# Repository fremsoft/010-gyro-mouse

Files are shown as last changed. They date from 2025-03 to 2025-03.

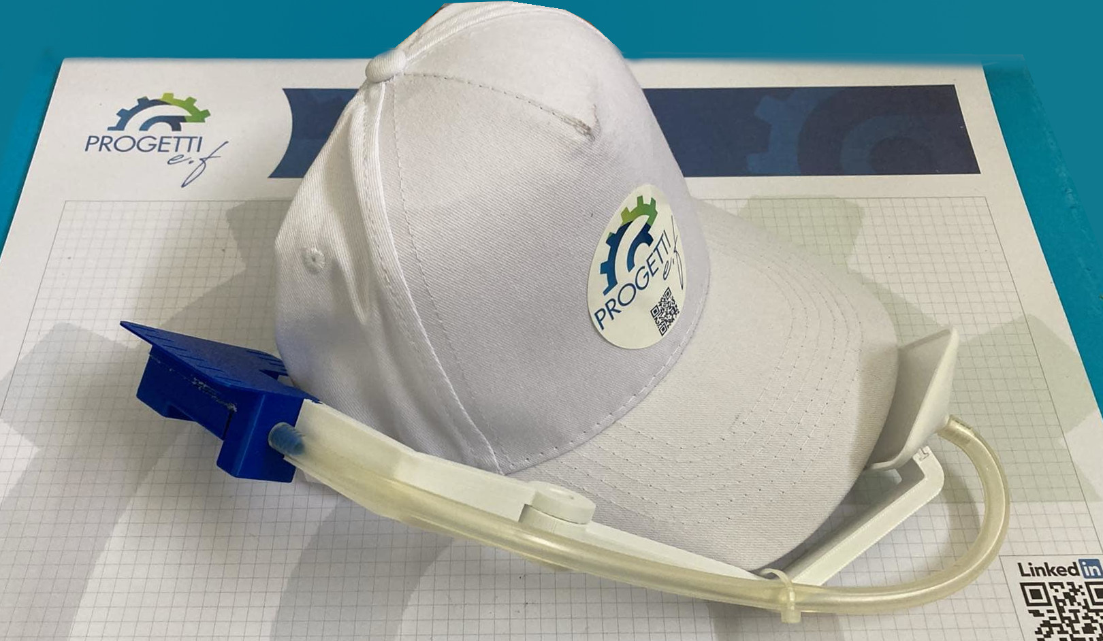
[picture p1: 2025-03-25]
hardware/gyro-mouse.jpg

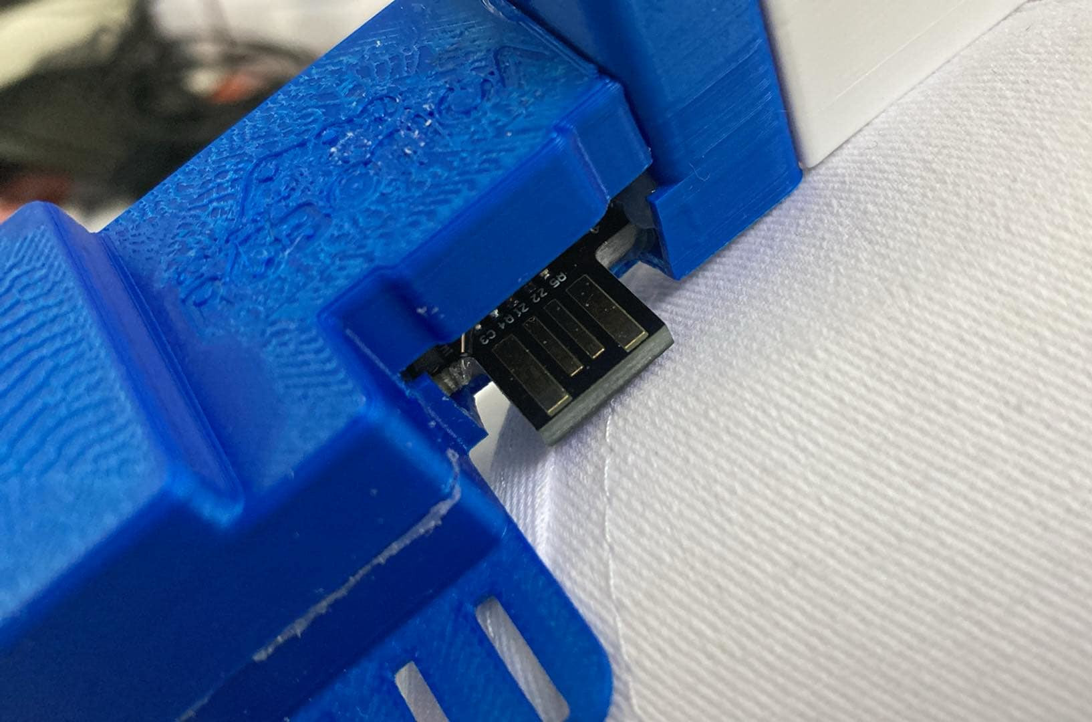
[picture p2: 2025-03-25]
hardware/dettaglio-gyro-mouse.jpg

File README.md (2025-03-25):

# 🖱️ Gyro Mouse – Controllo del Mouse con Inclinazione e Soffio

Il **Gyro Mouse** è un innovativo sistema di puntamento che consente di controllare il cursore del **mouse** attraverso l’**inclinazione della testa** e di simulare i click con il **soffio**. Questo dispositivo è stato progettato per offrire un'alternativa accessibile e intuitiva al tradizionale mouse.

## 📌 Caratteristiche
- **Controllo del cursore** tramite inclinazione della testa (coordinate assolute)
- **Emulazione dei click** con il soffio in un apposito imbuto
- **Compatibile con risoluzione 1920x1080**
- Basato su **Beetle (ATmega32U4)** o **Arduino Micro** o **Arduino Leonardo** per il supporto nativo USB
- Sensori utilizzati:
  - **MPU-6050** per rilevare l’inclinazione X-Y-Z
  - **BMP180** per il riconoscimento del soffio
- Progettato per il **fai-da-te** e l’integrazione in progetti di accessibilità

## 🎮 Modalità di Controllo
- **Inclinazione della testa** → Sposta il mouse su schermo
- **1 soffio breve** → Click sinistro
- **2 soffi brevi** → Doppio click
- **3 soffi brevi** → Click destro
- **Soffio prolungato** → Trascinamento

## 📂 Struttura del Repository
- `code/` → Contiene il codice sorgente del firmware
- `hardware/` → Schemi e dettagli sui componenti
- `docs/` → Guide e documentazione tecnica

## 🔧 Requisiti
Per costruire e utilizzare il Gyro Mouse, avrai bisogno di:
- **Beetle (ATmega32U4)**
- **MPU-6050 (accelerometro e giroscopio)**
- **BMP180 (sensore di pressione barometrica)**
- **Arduino IDE** per programmare il firmware
- **Cavi e connettori** per il cablaggio

## 📖 Istruzioni per l’Uso
1. **Scarica il codice** da questo repository
2. **Carica il firmware** su Beetle con Arduino IDE
3. **Collega i sensori** secondo lo schema fornito
4. **Indossa il dispositivo e testa il controllo del mouse** 🖱️

## 🎥 Video Dimostrativi
Guarda il progetto in azione su YouTube:
- [Gyro Mouse – in costruzione](#)

## 💡 Contribuisci
Vuoi migliorare il progetto? Sentiti libero di **fare fork del repository** e proporre modifiche tramite una pull request! Idee, miglioramenti e test sono sempre benvenuti.

## 📩 Contatti
Per domande, suggerimenti o collaborazioni, puoi contattarmi tramite [email] o aprire una issue su GitHub.

---  
✨ _Impara Giocando – Scuola di Robotica e Meccatronica_ ✨

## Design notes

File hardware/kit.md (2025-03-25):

# Materiale Utilizzato

Questo progetto utilizza componenti specifici per la realizzazione di un sistema basato su Arduino Micro/Leonardo con ATmega32U4.
Di seguito trovi l'elenco dei materiali necessari con i relativi link per l'acquisto.

## 🛠️ Componenti

- [ARDUINO BEETLE](https://amzn.to/4c5joW2) 
- [ARDUINO MICRO](https://amzn.to/421yWWj) 
- [MPU-6050](https://amzn.to/4iZpiKA)
- [BMP180](https://amzn.to/4iZpiKA)

Questi componenti vanno assemblati seguendo le indicazioni riportate nel video.

Buon divertimento con il tuo progetto! 🚀

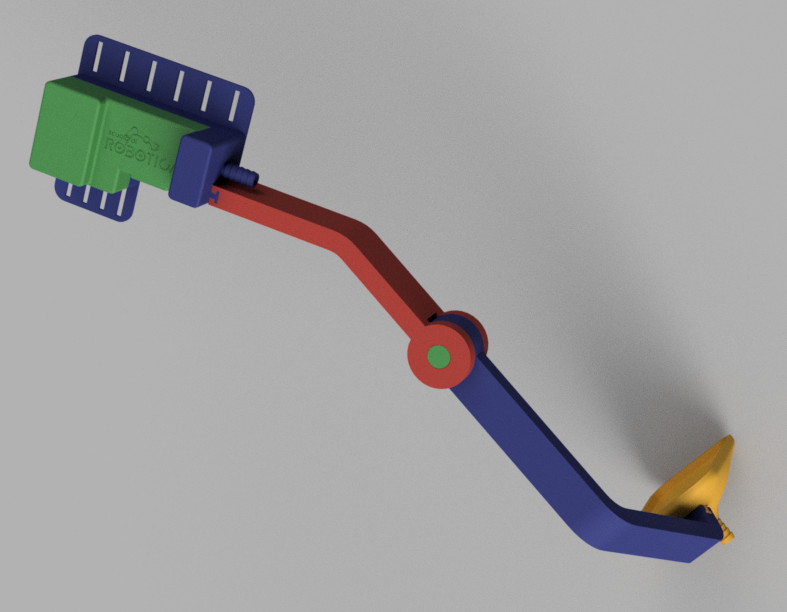
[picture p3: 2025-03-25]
hardware/GYRO-MOUSE v20.jpg

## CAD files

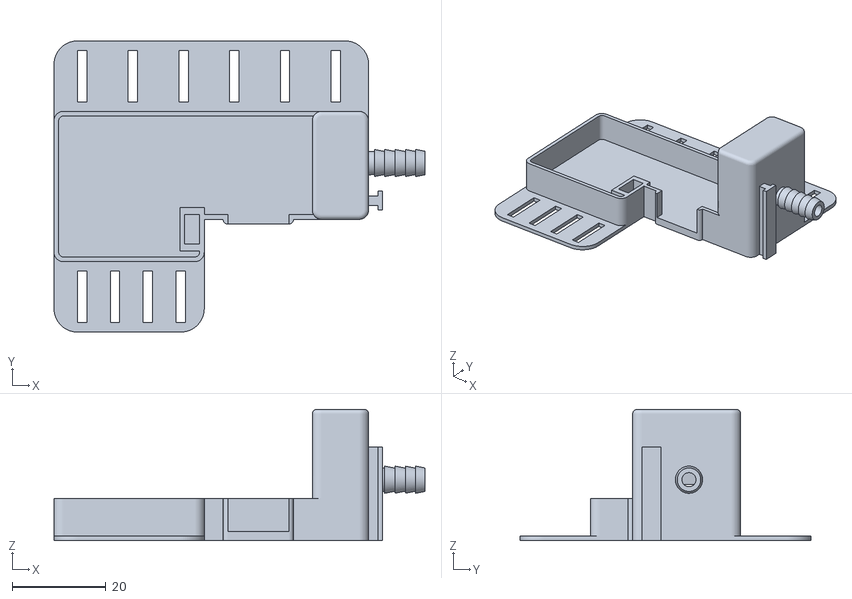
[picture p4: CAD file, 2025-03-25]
hardware/fusion360/stl/part1.stl
79.0 x 62.0 x 28.0

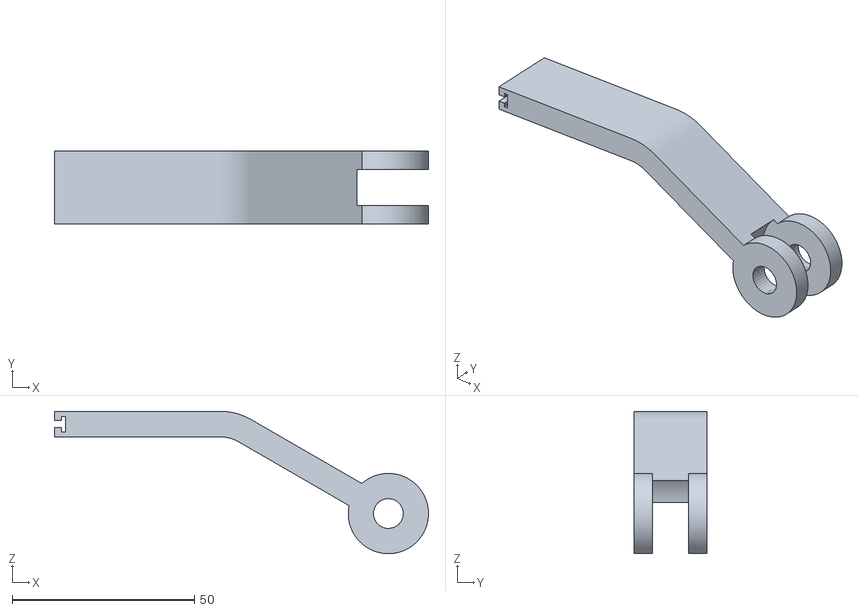
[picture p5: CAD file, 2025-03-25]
hardware/fusion360/stl/part5.stl
102.6 x 20.0 x 39.0

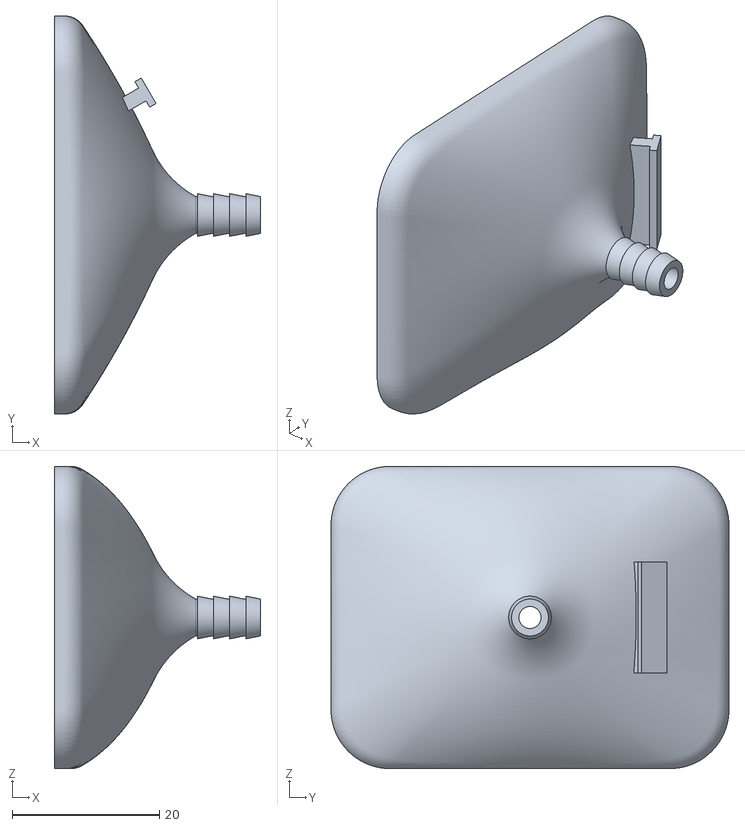
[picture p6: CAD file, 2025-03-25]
hardware/fusion360/stl/part4.stl
28.0 x 54.0 x 41.0

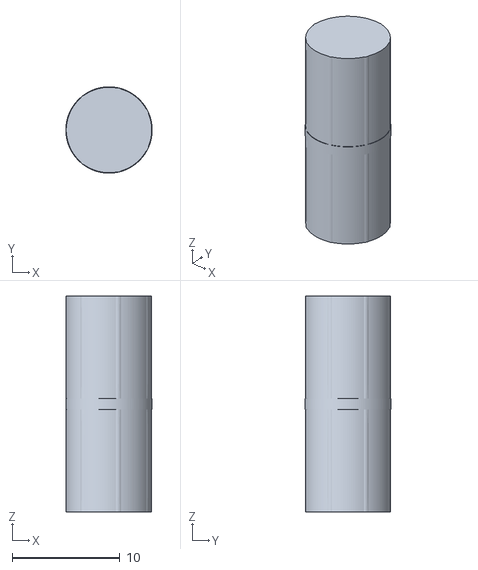
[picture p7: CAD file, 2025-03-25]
hardware/fusion360/stl/part7.stl
8.00 x 8.00 x 20.0

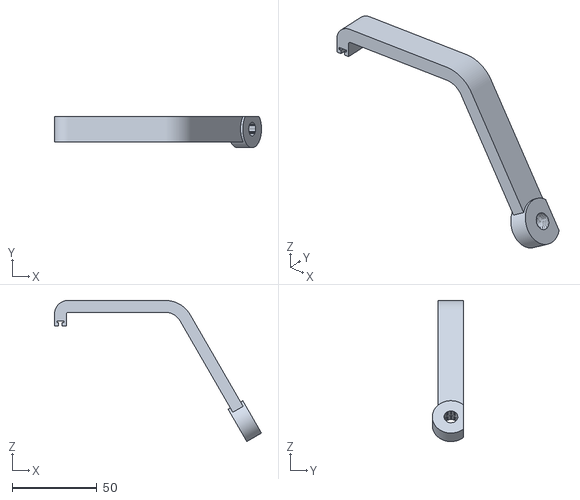
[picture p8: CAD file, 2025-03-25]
hardware/fusion360/stl/part6.stl
121.8 x 18.5 x 83.1

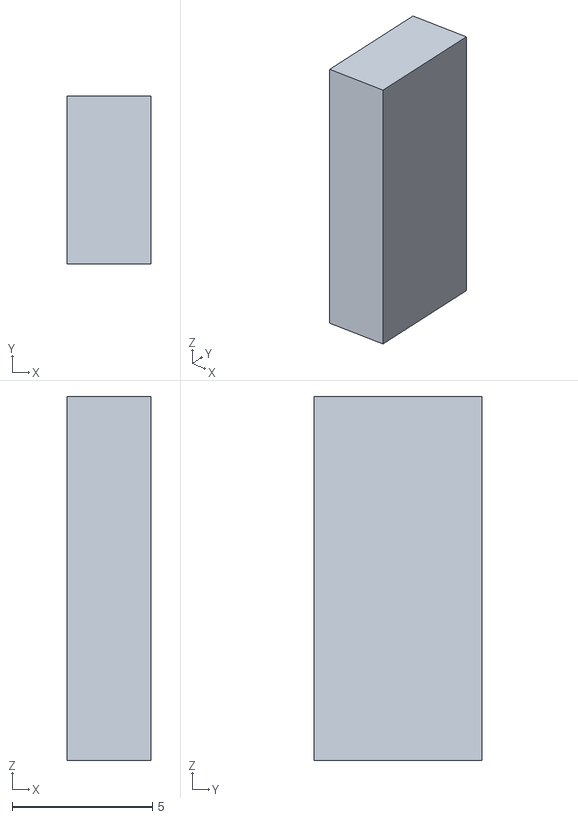
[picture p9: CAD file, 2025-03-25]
hardware/fusion360/stl/part3.stl
3.00 x 6.00 x 13.0

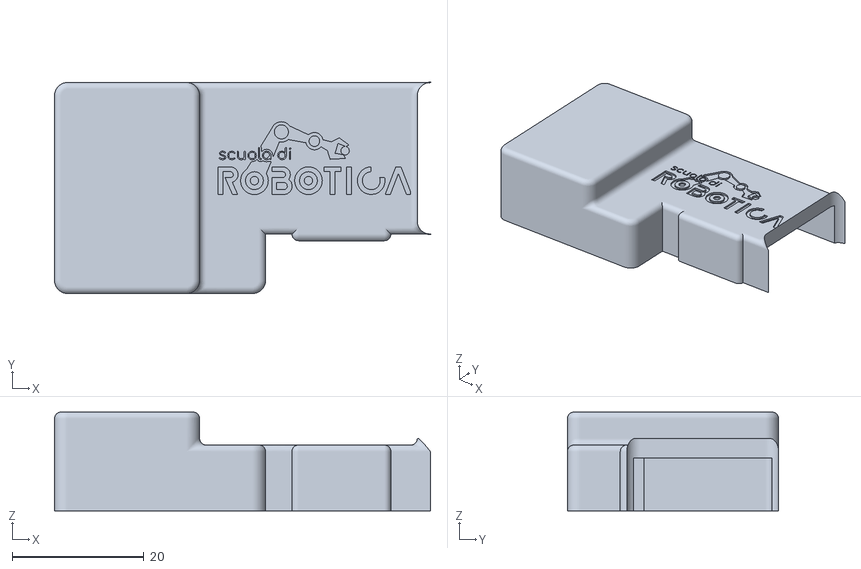
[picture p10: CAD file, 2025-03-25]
hardware/fusion360/stl/part2.stl
57.0 x 32.0 x 15.0

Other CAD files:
hardware/fusion360/GYRO-MOUSE v19.f3z

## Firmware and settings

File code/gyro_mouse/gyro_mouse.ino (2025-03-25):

#include <Adafruit_BMP085.h>
#include <Adafruit_MPU6050.h>
#include <Adafruit_Sensor.h>
#include <Wire.h>

#include <AbsMouse.h>

#define CLICK_TH        60
#define UNCLICK_TH      40
#define T_MIN_CLICK_MS 500

// Connect VCC of the BMP085 sensor to 3.3V (NOT 5.0V!)

Adafruit_BMP085 bmp;
Adafruit_MPU6050 mpu;

int32_t p, fp;
bool clicked;
int32_t t0_click, t1_click, t2_click, t_unclick;
float axf, ayf, azf;
int32_t x, y, xp, yp;


void setup() {
  Serial.begin(9600);

  if (!bmp.begin()) {
    Serial.println("Could not find a valid BMP085 sensor, check wiring!");
    while (1) {}
  }

  if (!mpu.begin()) {
    Serial.println("Failed to find MPU6050 chip");
    while (1) {
      delay(10);
    }
  }
  Serial.println("MPU6050 Found!");

  delay(2000);

  mpu.setAccelerometerRange(MPU6050_RANGE_2_G);
  Serial.print("Accelerometer range set to: ");
  switch (mpu.getAccelerometerRange()) {
    case MPU6050_RANGE_2_G:
      Serial.println("+-2G");
      break;
    case MPU6050_RANGE_4_G:
      Serial.println("+-4G");
      break;
    case MPU6050_RANGE_8_G:
      Serial.println("+-8G");
      break;
    case MPU6050_RANGE_16_G:
      Serial.println("+-16G");
      break;
  }
  mpu.setGyroRange(MPU6050_RANGE_250_DEG);
  Serial.print("Gyro range set to: ");
  switch (mpu.getGyroRange()) {
    case MPU6050_RANGE_250_DEG:
      Serial.println("+- 250 deg/s");
      break;
    case MPU6050_RANGE_500_DEG:
      Serial.println("+- 500 deg/s");
      break;
    case MPU6050_RANGE_1000_DEG:
      Serial.println("+- 1000 deg/s");
      break;
    case MPU6050_RANGE_2000_DEG:
      Serial.println("+- 2000 deg/s");
      break;
  }

  mpu.setFilterBandwidth(MPU6050_BAND_5_HZ);
  Serial.print("Filter bandwidth set to: ");
  switch (mpu.getFilterBandwidth()) {
    case MPU6050_BAND_260_HZ:
      Serial.println("260 Hz");
      break;
    case MPU6050_BAND_184_HZ:
      Serial.println("184 Hz");
      break;
    case MPU6050_BAND_94_HZ:
      Serial.println("94 Hz");
      break;
    case MPU6050_BAND_44_HZ:
      Serial.println("44 Hz");
      break;
    case MPU6050_BAND_21_HZ:
      Serial.println("21 Hz");
      break;
    case MPU6050_BAND_10_HZ:
      Serial.println("10 Hz");
      break;
    case MPU6050_BAND_5_HZ:
      Serial.println("5 Hz");
      break;
  }

  clicked = false;
  t0_click = t1_click = t2_click = t_unclick = 0;

  fp = (float)bmp.readPressure();

  axf = ayf = azf = 0.0;
  x = y = 0;
  xp = yp = -1;

  AbsMouse.init(1920, 1080);  // full HD
}

void loop() {
  int32_t t;
  sensors_event_t a, g, temp;
  mpu.getEvent(&a, &g, &temp);

  axf = ((49.0 * axf) + a.acceleration.x) / 50.0;
  ayf = ((49.0 * ayf) + a.acceleration.y) / 50.0;
  azf = ((49.0 * azf) + a.acceleration.z) / 50.0;

  y = constrain(
    map((long)(10000.0 * atan2(axf, ayf)), -1000, 1000, 1080, 0),
    0, 1080);
  x = constrain(
    map((long)(10000.0 * atan2(azf, ayf)), -1000, 1000, 1920, 0),
    0, 1920);

  p = (float)bmp.readPressure();
  fp = ((fp * 999.0) + p) / 1000.0;

  t = millis();
  if ((!clicked) && (abs(fp - p) > CLICK_TH)) {
    clicked = true;
    if ((t - t2_click) > T_MIN_CLICK_MS) {
      /* primo impulso */
      t0_click = t1_click = t2_click = t;
//Serial.println("primo");
    }
    else if ((t - t0_click) < T_MIN_CLICK_MS) {
      /* secondo impulso */
      t1_click = t2_click = t;
//Serial.println("secondo");
    }    
    else if ((t - t1_click) < T_MIN_CLICK_MS) {
      /* terzo impulso di fila */
      t2_click = t;
//Serial.println("terzo");
    }    
  }
  
  if (clicked) {
    /* se è passato il tempo clicco sinistro */
    if ((t - t0_click) > T_MIN_CLICK_MS) {
      AbsMouse.press(MOUSE_LEFT);
//Serial.println("click");
    }

    /* quando ho rilasciato, entro il tempo aspetto e valuto */
    if (abs(fp - p) < UNCLICK_TH) {
      /* preparo la variabile clicked per accettare altri click */
      clicked = false;
    }
  }
  else {
    /* se è passato il tempo rilascio sinistro */
    if ((t - t2_click) > T_MIN_CLICK_MS) {
      if (t0_click != 0) {
        if (t0_click == t1_click) {
          /* click semplice */
//Serial.println("click semplice");
          AbsMouse.press(MOUSE_LEFT);
          delay(100);
          AbsMouse.release(MOUSE_LEFT);
        }
        else 
        if (t1_click == t2_click) {
          /* doppio click */
//Serial.println("doppio click");
          AbsMouse.press(MOUSE_LEFT);
          delay(100);
          AbsMouse.release(MOUSE_LEFT);
          delay(100);
          AbsMouse.press(MOUSE_LEFT);
          delay(100);
          AbsMouse.release(MOUSE_LEFT);
        }
        else {
          /* triplo click == tasto destro */
//Serial.println("triplo click");
          AbsMouse.release(MOUSE_LEFT);
          AbsMouse.press(MOUSE_RIGHT);
          delay(100);
          AbsMouse.release(MOUSE_RIGHT);
        }
        t0_click = 0;
      }
    }
  }

  if ((abs(x - xp) > 10) || (abs(y - yp) > 10)) {
    AbsMouse.move(x, y);

    xp = x;
    yp = y;
  }

  //Serial.print(p);
  //Serial.print(",");
  //Serial.println(fp);
  //Serial.print(",");
  //Serial.print(clicked);
  //Serial.print(",");
  //Serial.print(x);
  //Serial.print(",");
  //Serial.println(y);
}
